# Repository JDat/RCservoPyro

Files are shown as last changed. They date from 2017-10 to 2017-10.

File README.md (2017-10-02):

# RCservoPyro
Converts from RC servo input to ON/OFF for pyro charge or ON/OFF switch

This project read input from one RC servo channel and turns on output. Useful for ON/OFF control from RC. Have Normal Open or Normal Closed version (depending on soldered components). Additional Status LED for pyro charge continuity check.

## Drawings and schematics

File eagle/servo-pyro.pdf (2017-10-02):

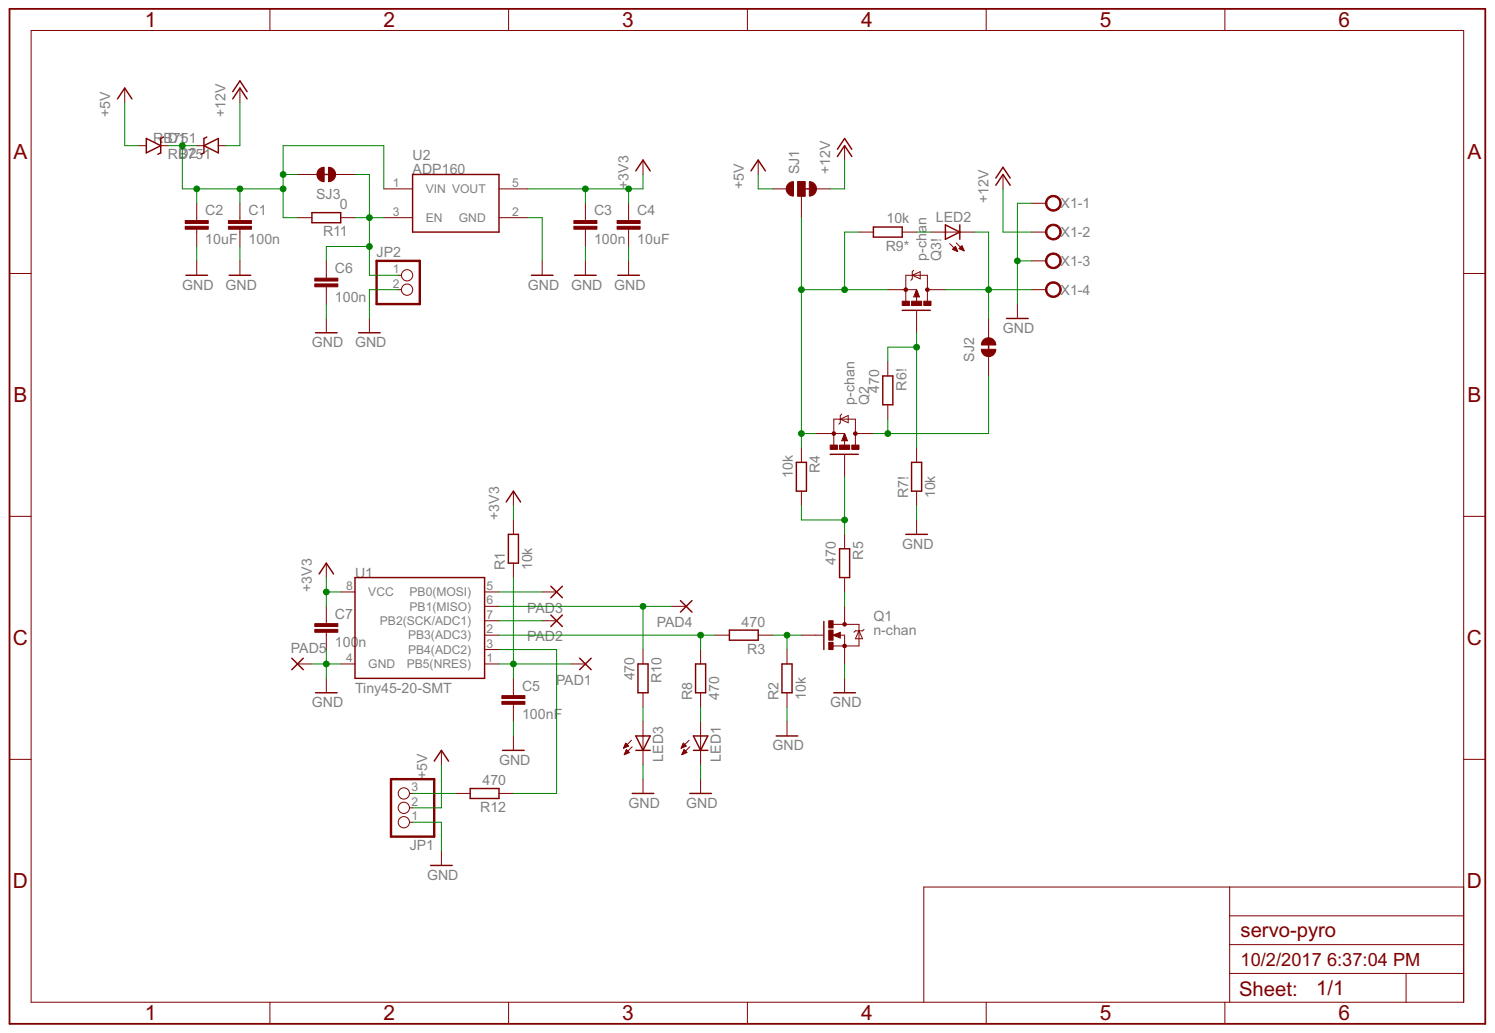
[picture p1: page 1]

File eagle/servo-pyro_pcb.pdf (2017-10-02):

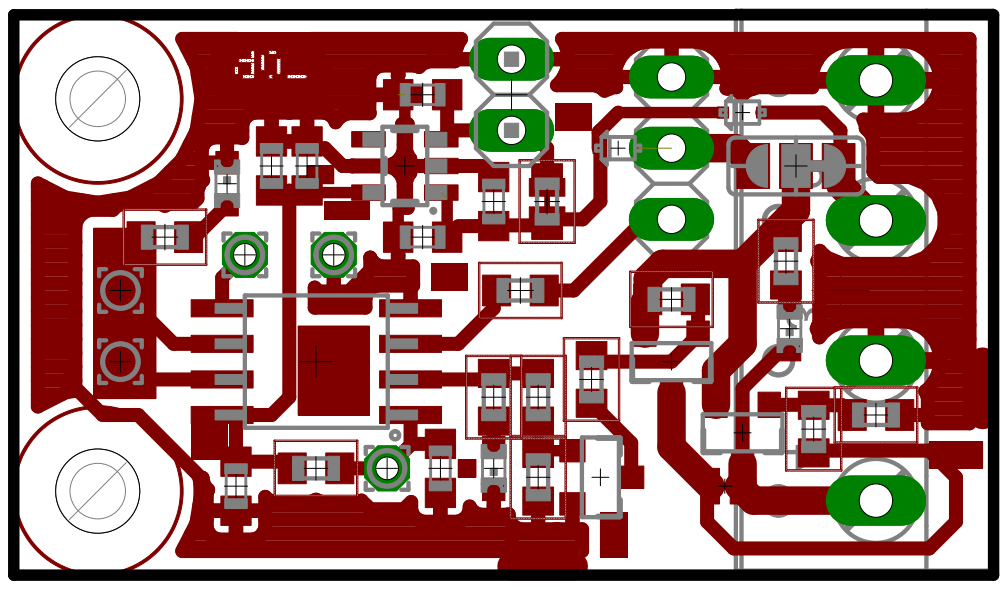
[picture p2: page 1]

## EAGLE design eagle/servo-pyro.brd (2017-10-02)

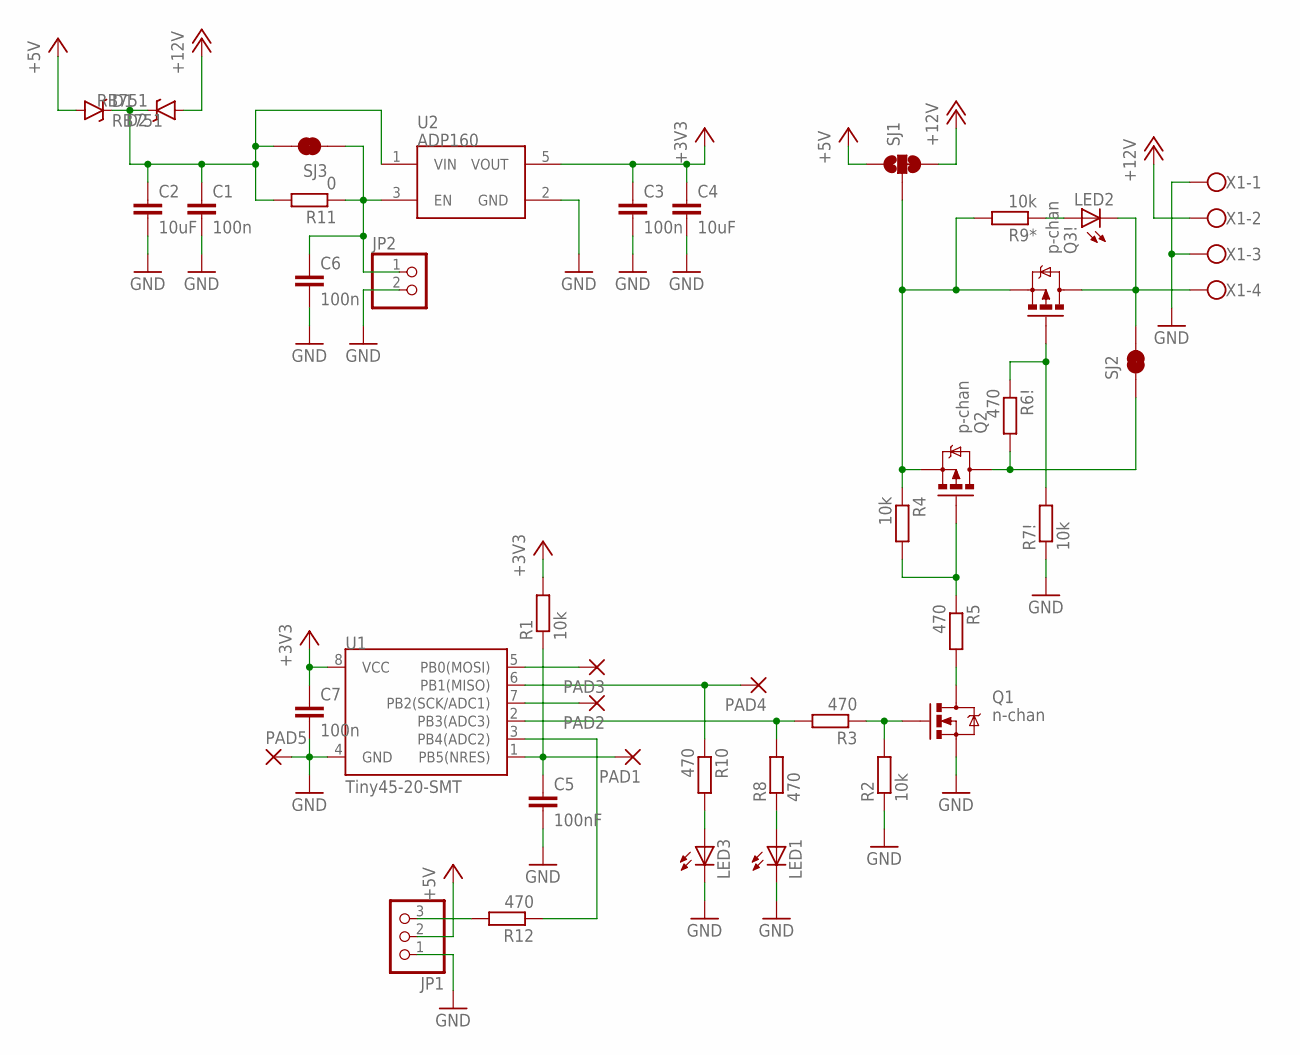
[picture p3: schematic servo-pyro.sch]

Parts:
C1, C3, C6, C7: 100n; C0603K
C2, C4: 10uF; C0603K
C5: 100nF; C0603K
D1, D2: RB751; SOD-523
JP1: PINHD-1X3; 1X03
JP2: PINHD-1X2; 1X02
LED1, LED2, LED3: LEDCHIPLED_0603; CHIPLED_0603
PAD1, PAD2, PAD3, PAD4, PAD5: 1,6/0,8
Q1: n-chan; SOT23-3
Q2, Q3!: p-chan; SOT23-3
R1, R2, R4, R7!, R9*: 10k; R0603
R3, R5, R6!, R8, R10, R12: 470; R0603
R11: 0; R0603
SJ1: JUMPER-PAD-3-2OF3_NC_BY_TRACE_LARGE; PAD-JUMPER-3-2OF3_NC_BY_TRACE_YES_SILK_LARGE
SJ2, SJ3: JUMPER-PAD-2-NC_BY_TRACENO_SILK; PAD-JUMPER-2-NC_BY_TRACE_NO_SILK
U1: Tiny45-20-SMT; SO08-EIAJ
U2: ADP160; SOT23-5
X1: W237-4

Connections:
+3V3: C3.1, C4.1, C7.1, R1.2, U1.8 (VCC), U2.5 (VOUT)
+5V: D1.A, JP1.2, SJ1.1
+12V: D2.A, SJ1.3, X1.2
GND: C1.2, C2.2, C3.2, C4.2, C5.2, C6.2, C7.2, JP1.1, JP2.2, LED1.C, LED3.C, PAD5.1, Q1.2 (S), R2.1, R7!.1, U1.4 (GND), U2.2 (GND), X1.1, X1.3
unnamed: C5.1, PAD1.1, R1.1, U1.1 (PB5(NRES))
unnamed: C6.1, JP2.1, R11.1, SJ3.1, U2.3 (EN)
unnamed: LED2.A, R9*.1
unnamed: C1.1, C2.1, D1.C, D2.C, R11.2, SJ3.2, U2.1 (VIN)
unnamed: PAD2.1, U1.7 (PB2(SCK/ADC1))
unnamed: PAD3.1, U1.5 (PB0(MOSI))
unnamed: Q3!.1 (G), R6!.1, R7!.2
unnamed: Q2.1 (G), R4.2, R5.1
unnamed: Q1.1 (G), R2.2, R3.1
unnamed: Q1.3 (D), R5.2
unnamed: LED1.A, R8.1
unnamed: R3.2, R8.2, U1.2 (PB3(ADC3))
unnamed: LED3.A, R10.2
unnamed: JP1.3, R12.2
unnamed: R12.1, U1.3 (PB4(ADC2))
unnamed: PAD4.1, R10.1, U1.6 (PB1(MISO))
PWR_IN: Q2.2 (S), Q3!.2 (S), R4.1, R9*.2, SJ1.2
PWR_ON: Q2.3 (D), R6!.2, SJ2.1
PWR_OUT: LED2.C, Q3!.3 (D), SJ2.2, X1.4

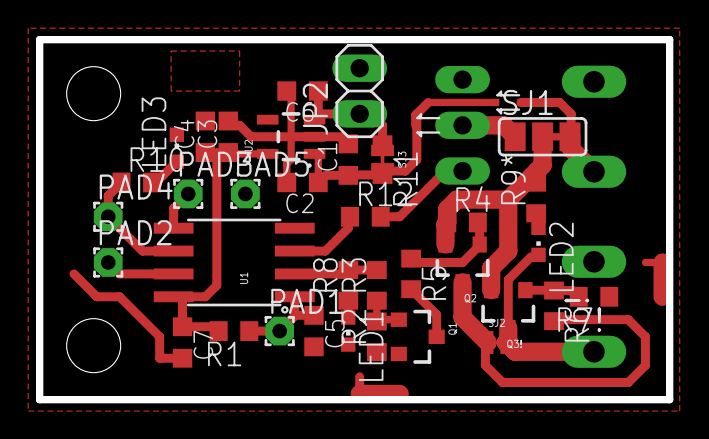
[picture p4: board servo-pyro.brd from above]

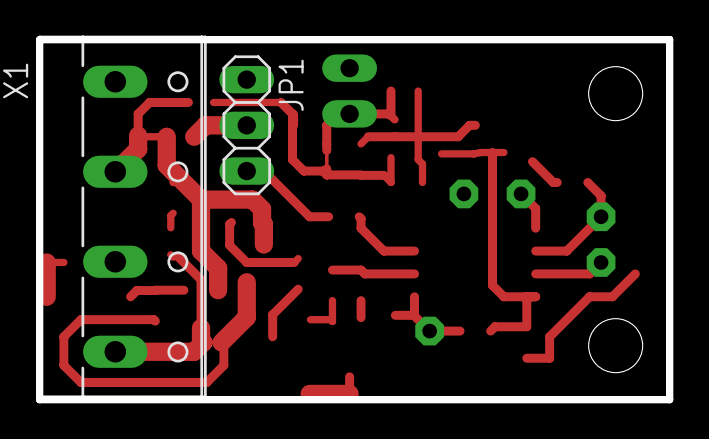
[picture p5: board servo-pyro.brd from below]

Board: 2 copper layers, 35.0 x 20.0 mm, 40 parts (2 on the bottom side), 23 nets.

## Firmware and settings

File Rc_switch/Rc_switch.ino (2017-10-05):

//-U lfuse:w:0xe2:m -U hfuse:w:0xd7:m -U efuse:w:0xff:m 

// nostrades slieksnis pie kura jabutt OK
#define treshold 1600

//pulseIn timeout mikrosekundes. Skatit Arduino reference manual
#define pulseTimeout 50000

#define relejs 3
#define servoIn 4
#define statusLedPin 1


const uint8_t kTIMER1_DIV4096 = 0b1101;

unsigned long  ins; 

void setup() {
  //varbut vajag INPUT un pielodet 100K pretestibu pret GND
  pinMode(servoIn,INPUT_PULLUP);
  pinMode(relejs,OUTPUT);
  pinMode(statusLedPin,OUTPUT);

  cli();
  TCCR1 = _BV(CTC1) | kTIMER1_DIV4096;
  //TCCR1 = kTIMER1_DIV512;
  OCR1C = 193;
  OCR1A = OCR1C;
  TIMSK |= _BV(OCIE1A);
  sei();

  //Uz atTiny85 nav seriala porta, izmetam ara
  //Serial.begin(9600);
}

void loop() {  
  ins = pulseIn(servoIn, HIGH, pulseTimeout); 
  if (ins > treshold) {
    digitalWrite(relejs,HIGH);
  }
  else {
    digitalWrite(relejs,LOW);
  }

//Serial.println(ins, DEC);
//Serial.println(relejs, BIN);

// mums vairs nevajag pauzi, visam jastrada nepartraukti.
// Ja ir sudi tad pieliekam delay 10 50 vai cik vajag
  //delay(100);
}

ISR(TIMER1_COMPA_vect) {
  static bool ledState;
  static uint8_t cnt1;
  
  if (++cnt1 >= 30) {
    cnt1 = 0;
  }
  if (ins==0) {
    ledState=!ledState;
    if (ledState){
          digitalWrite(statusLedPin,HIGH);
    } else {
      digitalWrite(statusLedPin,LOW);
    }
  } else {
    //if (cnt1 < 2 || (cnt1 > 8 && cnt1 < 15)) digitalWrite(statusLedPin,HIGH);
    if ((cnt1 > 8 && cnt1 < 15)) digitalWrite(statusLedPin,HIGH);
    else digitalWrite(statusLedPin,LOW);
  }
}

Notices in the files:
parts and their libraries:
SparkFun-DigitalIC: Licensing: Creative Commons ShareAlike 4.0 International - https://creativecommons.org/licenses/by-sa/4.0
